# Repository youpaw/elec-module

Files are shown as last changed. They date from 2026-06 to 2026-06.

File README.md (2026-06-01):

# FLIPPER 42 — Electronics Project

A custom device inspired by the Flipper Zero, capable of reading, cloning, and emitting NFC & RFID signals. It features an external coaxial antenna, optional infrared transmission, a custom firmware display, and SD card storage for saved data.

---

## Overview

| Feature | Description |
|---|---|
| **Controls** | 5-button navigation: ◄ ▼ ● ▲ ► (Left, Down, Select, Up, Right) |
| **Power** | 5V DC supply |
| **Storage** | SD card module for firmware and saved signals (NFC dumps, etc.) |
| **Antenna** | External coaxial antenna |
| **Additional** | IR emitter for infrared signal transmission |

---

## Components

### NFC Reader
**IC:** ST25R3916B-AQWT  
High-performance NFC frontend supporting reader/writer and card emulation modes.  
📄 [Datasheet](https://www.st.com/resource/en/datasheet/st25r3916b.pdf)
### RFID Reader
**IC:** EM4095  
125 kHz RFID transceiver for LF tag reading and writing.  
📄 [Datasheet](https://www.emmicroelectronic.com/sites/default/files/products/datasheets/em4095_ds.pdf)

### SD Card Module
**Part Number:** 1040310811 (Molex)  
Micro SD card socket for firmware storage and signal database.  
📄 [Datasheet](https://www.molex.com/en-us/products/part-detail-pdf/1040310811?display=pdf)

---

## Materials

| Qty | Component | Part Number / Symbol | Notes |
|-----|---|---|---|
| 1 | NFC Transceiver | ST25R3916B-AQWT | |
| 1 | RFID Transceiver | EM4095 | 125 kHz |
| 1 | SD Card Socket | 1040310811 | Molex |
| 1 | Coaxial Antenna | — | External |
| 1 | IR LED / Transmitter | — | Optional |
| 1 | Display Module | — | For custom firmware UI |
| 5 | Tactile Switches | — | Navigation buttons |
| — | Power Regulation | — | 5V input |

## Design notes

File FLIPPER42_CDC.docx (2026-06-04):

CAHIER DES CHARGES

Specifications Document

FLIPPER 42

Portable Multi-Protocol Security Research Device

Project | FLIPPER 42
School | École 42 Paris
Module | Electronics / Embedded Systems
Document type | Cahier des Charges (CDC)
Version | 1.0
Date | June 2026
Status | Draft - for academic validation
Authors | FLIPPER 42 Team - 42 Paris

# Table of Contents

1. Introduction 3

1.1 Project Overview 3

1.2 Scope 3

1.3 Definitions & Abbreviations 3

2. Functional Requirements 4

2.1 Core Functions 4

2.2 Sub-GHz (CC1101) 4

2.3 NFC (ST25R3916) 4

2.4 RFID (EM4095) 4

2.5 User Interface 4

3. Hardware Architecture 5

3.1 System Block Diagram Overview 5

3.2 Microcontroller - ATmega2560 5

3.3 Communication Buses 6

3.4 Power Supply 6

4. Non-Functional Requirements 7

4.1 Physical 7

4.2 Electrical 7

4.3 Software & Firmware 7

4.4 Safety 7

5. Bill of Materials (BoM) 7

6. Implementation Procedure 8

6.1 Development Phases 8

7. Acceptance Criteria & Test Plan 8

7.1 Functional Tests 8

7.2 Compliance Checks 9

8. References & Datasheets 9

9. Notes 9

9.1 Hardware Block Diagram Description 9

# 1. Introduction

## 1.1 Project Overview

The FLIPPER 42 is a portable, open-hardware multifunctional device designed for interaction with various electronic access-control and radio-frequency systems. Inspired by the Flipper Zero, the project explores low-level embedded systems design and RF security research using an alternative hardware architecture built around the ATmega2560 microcontroller.

The device is conceived for:

- Educational purposes and academic training in embedded systems
- Security research and ethical hacking activities
- Reading, cloning, and replaying NFC/RFID credentials on authorised systems
- Sub-GHz radio signal acquisition and controlled reproduction
- Hands-on exploration of hardware security protocols

## 1.2 Scope

This document describes the technical and functional specifications of the FLIPPER 42 hardware platform, covering architecture, communication modules, power supply, firmware behaviour, and acceptance criteria. It serves as the reference baseline for the 42 Paris electronics module validation.

## 1.3 Definitions & Abbreviations

Acronym / Term | Definition
CDC | Cahier des Charges
MCU | Microcontroller Unit
RFID | Radio-Frequency IDentification
NFC | Near-Field Communication
Sub-GHz | Radio frequencies below 1 GHz (e.g. 433 MHz, 868 MHz)
SPI | Serial Peripheral Interface - synchronous serial bus
I2C | Inter-Integrated Circuit - two-wire serial bus
UART | Universal Asynchronous Receiver-Transmitter
BMS | Battery Management System
ADC | Analog-to-Digital Converter
GPIO | General-Purpose Input/Output
EEPROM | Electrically Erasable Programmable Read-Only Memory
LF | Low Frequency (125 kHz RFID band)
HF | High Frequency (13.56 MHz NFC band)

# 2. Functional Requirements

## 2.1 Core Functions

The device shall implement the following primary functions:

1. RF Signal Detection & Identification - detect and classify incoming radio signals in supported bands
1. NFC Credential Reading - read and decode ISO 14443 and ISO 15693 compliant tags at 13.56 MHz
2. RFID Credential Reading - read 125 kHz LF tags using the EM4095 transceiver
3. Data Storage - persist captured payloads, signal recordings, and configurations on microSD
4. Signal Replay - reproduce previously recorded signals upon authorised user action
5. External Expansion - expose hardware interfaces (SPI, UART, GPIO) for optional add-on modules

## 2.2 Sub-GHz (CC1101)

The CC1101 low-power Sub-1 GHz RF transceiver shall support:

- Single-band operation dedicated exclusively to the 433 MHz ISM band
- Serial modes for reading, capturing, and replaying raw RF frames
- A path to a physical coaxial connector for an external 433 MHz antenna
- Communication with the MCU via a 4-wire SPI interface at 3.3 V

## 2.3 NFC (ST25R3916)

The ST25R3916B-AQWT high-performance NFC frontend shall support:

- Reader/Writer mode for ISO 14443-A/B and ISO 15693 tagsAlso @
- Card emulation mode (Type A / Type B)
- Reading, storing, and replaying NDEF messages and raw tag dumps
- Communication with the MCU via SPI at 3.3 V

## 2.4 RFID (EM4095)

The EM4095 125 kHz RFID transceiver shall:

- Read EM4100-compatible and compatible LF tags
- Provide demodulated data via GPIO/UART to the MCU
- Store captured UIDs and data payloads to microSD

## 2.5 User Interface

The device shall provide a 6-button navigation interface:

Button | Direction | Function
◄ | Left | Navigate left / back
▼ | Down | Scroll down / decrease value
● | Select | Confirm / enter
▲ | Up | Scroll up / increase value
► | Right | Navigate right / forward
⮐ | Outside / Isolated | Back / Return

An OLED display (connected via I2C) shall provide a menu-driven interface showing:

- Main menu with module selection
- Real-time signal activity and status
- Stored file browser for saved captures
- Battery level and system status

# 3. Hardware Architecture

## 3.1 System Block Diagram Overview

The hardware architecture is centred on the ATmega2560 MCU and interconnects the following subsystems via dedicated bus protocols as described in the uploaded block diagram:

Subsystem | Interface | Voltage | Notes
MCU - ATmega2560 | Central | 5 V | Main controller, 256 KB Flash, 8 KB SRAM, 4 KB EEPROM
OLED Display | I2C | 3.3/5V | ER-OLED015-2Y, 128×64 px
microSD Card | SPI | 3.3 V | FAT32 formatted; stores captures & config
CC1101 Sub-GHz Transceiver | SPI | 3.3 V | Level-shifted; 433 MHz only; external antenna
ST25R3916 NFC Frontend | SPI | 3.3 V | ISO 14443/15693 reader + card emulation
EM4095 RFID Transceiver | GPIO | 5 V | 125 kHz LF RFID
Battery + BMS | Power | 3.7 V | LiPo cell with protection circuit
USB / UART Bridge | UART | 5 V | PC connectivity, firmware upload
Buttons (5×) | GPIO | 3.3 V | Navigation; debounced in firmware
Level Shifter | Logic | 3.3/5V | Bidirectional; protects 3.3 V peripherals
Voltage Divider / ADC | Analog | Var. | Battery voltage sense via MCU ADC

## 3.2 Microcontroller - ATmega2560

The ATmega2560 (TQFP-100) is the central processing unit. Key specifications:

Parameter | Value
Architecture | 8-bit AVR RISC
Clock speed | Up to 16 MHz (external crystal)
Flash memory | 256 KB (in-system programmable)
SRAM | 8 KB
EEPROM | 4 KB
GPIO | 86 pins
SPI interfaces | 1× hardware SPI (shared with CC1101, SD, NFC)
I2C (TWI) | 1× hardware TWI (OLED)
UART | 4× hardware UART (1 used for USB bridge)
ADC | 16-channel, 10-bit
Timers | 6× (8-bit and 16-bit)
Operating voltage | 4.5 V – 5.5 V

## 3.3 Communication Buses

### 3.3.1 SPI Bus (3.3 V)

A single SPI bus (MOSI, MISO, SCK) serves the CC1101, microSD, and ST25R3916. Each peripheral is independently selected via a dedicated active-low CS (chip select) line driven by the MCU GPIO. The bus operates at 3.3 V logic; a bidirectional level shifter protects all 3.3 V devices from the 5 V MCU outputs.

### 3.3.2 I2C Bus

The I2C bus connects the OLED display to the MCU using standard 400 kHz fast-mode. Pull-up resistors (4.7 kΩ typical) shall be fitted on SDA and SCL lines.

### 3.3.3 UART

UART0 is routed to a USB-to-UART bridge IC (e.g. CH340G or CP2102) for PC connectivity. This enables firmware flashing via avrdude and runtime serial debugging at 115200 baud.

## 3.4 Power Supply

Domain | Source | Regulation | Consumers
5 V main | USB or LiPo via boost | LDO / boost converter | MCU, EM4095, USB bridge
3.3 V rail | AMS1117-3.3 or equiv. | LDO from 5 V | CC1101, NFC, OLED, SD, level shifter
Battery | LiPo 3.7 V / 1000 mAh+ | BMS + protection IC | System supply when off USB

The BMS shall provide over-charge, over-discharge, and short-circuit protection. A voltage divider on the battery line feeds the MCU ADC for state-of-charge estimation.

# 4. Non-Functional Requirements

## 4.1 Physical

Requirement | Target
Weight | TODO < 400g
Enclosure | PCB-mount shell Initially then 3D-printed
Connector | USB-C or Micro-USB for power and programming

## 4.2 Electrical

Requirement | Target
Supply input | 5 V via USB; 3.7 V LiPo battery
3.3 V rail | +-5% tolerance
Autonomy | TODO

## 4.3 Software & Firmware

- Firmware written in C using the “avr” library toolchain
- Menu-driven OLED interface with 5-button navigation
- FAT32 filesystem on microSD
- UART debug console at 115200 baud accessible via USB

## 4.4 Safety

The FLIPPER 42 shall be operated exclusively in compliance with applicable radio regulations.

The device is intended for educational and security research only.

# 5. Bill of Materials (BoM)

The following table lists the principal components identified for the FLIPPER 42 prototype. Quantities are for a single unit.

Qty | Component | Part Number | Interface | Notes
1 | MCU | ATmega2560-16AU | SPI/I2C/UART/GPIO | Main controller, TQFP-100
1 | Sub-GHz Transceiver | CC1101 | SPI 3.3 V | 433 MHz; external antenna
1 | NFC Frontend | ST25R3916B-AQWT | SPI 3.3 V | ISO 14443 / 15693
1 | RFID Transceiver | EM4095 | GPIO 5 V | 125 kHz LF RFID
1 | OLED Display | ER-OLED015-2 | I2C | 128×64 px
1 | microSD Socket | 1040310811 (Molex) | SPI 3.3 V | FAT32; micro-SD
1 | 3.3 V LDO | AMS1117-3.3 | Power | 300 mA min.
1 | Battery BMS | | Power | LiPo protection
1 | LiPo Battery | 3.7 V / 1000+ mAh | Power | Rechargeable
1 | Coaxial Antenna | 433 MHz SMA | RF | External removable
5 | Tactile Switches | Generic 6×6 mm | GPIO | Navigation buttons
-- | Passives (R, C, L) | Various | PCB | Per datasheet values

# 6. Implementation Procedure

## 6.1 Development Phases

Phase | Activity | Deliverable
1 - Design | Schematic capture, component selection, BOM validation | Schematic PDF, BoM spreadsheet
2 - PCB Layout | Routing, DRC KiCad Files | PCB fabrication order
3 - Prototyping | Breadboard / protoboard assembly and initial power-on | Powered prototype, voltage checks
4 - Firmware | Development per module (CC1101, NFC, RFID, SD) | Firmware repo, unit tests
5 - Integration | System integration, module interaction, OLED UI | Working integrated prototype
6 - Validation | Functional test against acceptance criteria | Test report
7 - Documentation | CDC finalisation, code documentation, README | Final CDC PDF, GitHub

# 7. Acceptance Criteria & Test Plan

## 7.1 Functional Tests

Test ID | Module | Procedure | Expected Result | Pass Criteria
T-01 | Power | Apply 5 V USB; measure 5 V and 3.3 V rails | Both rails within ±5% | Voltmeter reading in spec
T-02 | MCU | Flash blink firmware; observe LED | LED blinks at 1 Hz | Visible blink
T-03 | OLED | Flash display test; observe screen | All pixels lit, menu displayed | Visual Confirmation
T-04 | SD Card | Write and read test file via firmware | File written and read back correctly | Data integrity 100%
T-05 | CC1101 | Capture 433 MHz remote signal; display capture | Signal captured and stored on SD | Valid file on SD card
T-06 | CC1101 | Replay stored 433 MHz signal to target device | Target device responds | Repeatable successful replay
T-07 | NFC | Read ISO 14443-A tag; display UID on OLED | UID displayed correctly | Matches reference reader
T-08 | RFID | Read EM4100 125 kHz tag; display data | Tag data displayed correctly | Matches reference reader
T-09 | Battery | Operate 4 h on battery; monitor voltage | Device operational for ≥ 4 h | No shutdown under load
T-10 | Buttons | Press each button; verify OLED response | Correct navigation action per button | All 6 buttons functional

## 7.2 Compliance Checks

- All RF transmissions verified to comply with 433 MHz ISM band limits
- Device shall not transmit on unauthorised frequencies

# 8. References & Datasheets

Document | Source
ATmega2560 Datasheet | https://www.microchip.com/en-us/product/atmega2560
CC1101 Datasheet | https://www.ti.com/lit/ds/symlink/cc1101.pdf?ts=1780550466112
ST25R3916B Datasheet | https://www.st.com/resource/en/datasheet/st25r3916b.pdf
EM4095 Datasheet | https://www.emmicroelectronic.com/sites/default/files/products/datasheets/em4095_ds.pdf
microSD Socket (Molex) | Part 1040310811
Project GitHub Repository | https://github.com/youpaw/elec-module
Flipper Zero Reference | https://flipperzero.one

# 9. Notes

## 9.1 Hardware Block Diagram Description

The following block diagram shows the interconnections for the FLIPPER 42 system.

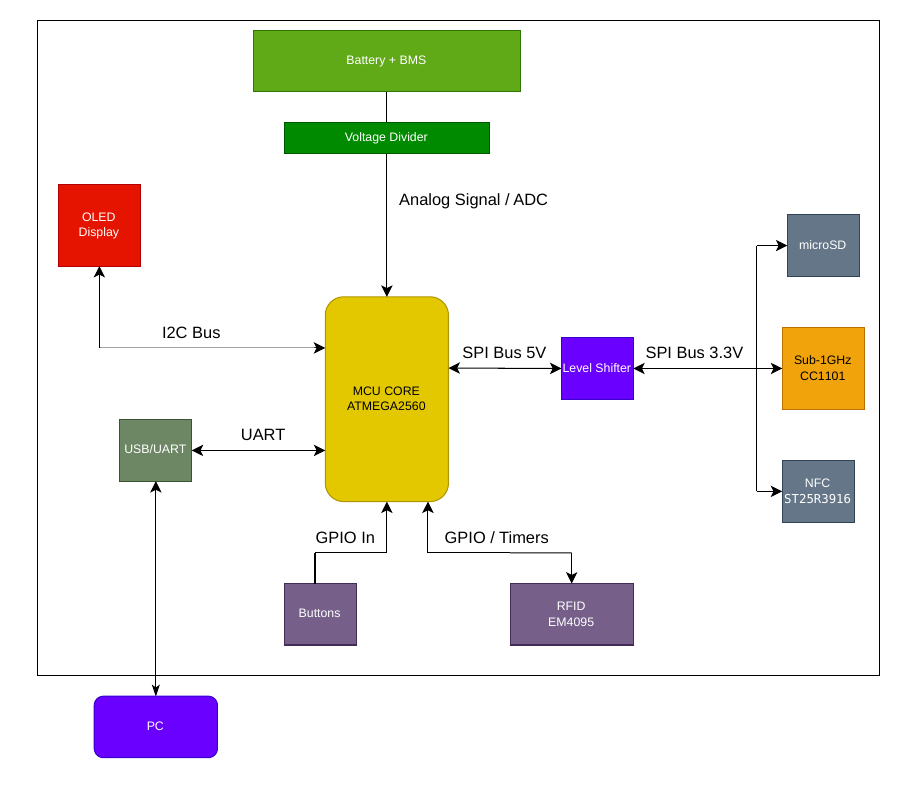
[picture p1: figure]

42Paris Page 11 / 11

FLIPPER 42 - Cahier des Charges (CDC) École 42 Paris

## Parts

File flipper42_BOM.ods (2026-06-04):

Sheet: Sheet1
Item | Designator | Quantity | Value/Part Name | Package / Footprint | Description | Manufacturer | Manufacturer Part Number | Supplier | Supplier Link | Unit Price | Total Price
1 | U1 | 1 | ATMEGA2560 | TQFP-100 | Microcontroller MCU | Microchip
2 | U3 | 1 | TXS0108E | TSSOP-20 | Voltage level shifter | Texas Instrument | TXS0108EPWR
3
4
5
6
7
8
9
10
11
12

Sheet: Sheet2
Item | Designator | Quantity | Value/Part Name | Package / Footprint | Description | Manufacturer | Manufacturer Part Number | Supplier | Supplier Link | Unit Price | Total Price
1 | U2 | 1 | CC1101 |  |  | Texas Instruments
2 | C51 | 1 | Capacitor 100 nF ± 10% | O402
3 | C81, C101 | 2 | Capacitor 27 pF ± 5% | O402
4 | C121 | 1 | Capacitor 3.9pF ± 0.25 pF | O402
5 | C122 | 1 | Capacitor 8.2 pF ± 0.5pF | O402
6 | C123 | 1 | Capacitor5.6 pF ± 0.5pF | O402
7 | C124, C125 | 2 | Capacitor 220 pF ± 5% | O402
8 | C131 | 1 | Capacitor 3.9pF ± 0.25 pF | O402 monolithic | Capacitor monolithic
9 | L121, L123, L131 | 2 | 27 nH ± 5% | O402 monolithic
10 | L122 | 1 | 22 nH ± 5% | O402 monolithic
11 | R171 | 1 | 56 kOhms ± 1% | O402
12 | XTAL | 1 | 26 MHz |  | 26 MHz SMD Crystal
13 |  | 1 | CON-SMA-EDGE-S |  | Connector Coaxial Female Socket Board Edge Mount 50Ohms | RF Solutions | CON-SMA-EDGE-S
14 | Atenna | 1 |  |  | Antenna Whip 433MHz

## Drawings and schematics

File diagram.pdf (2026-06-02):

## Analog Signal / ADC

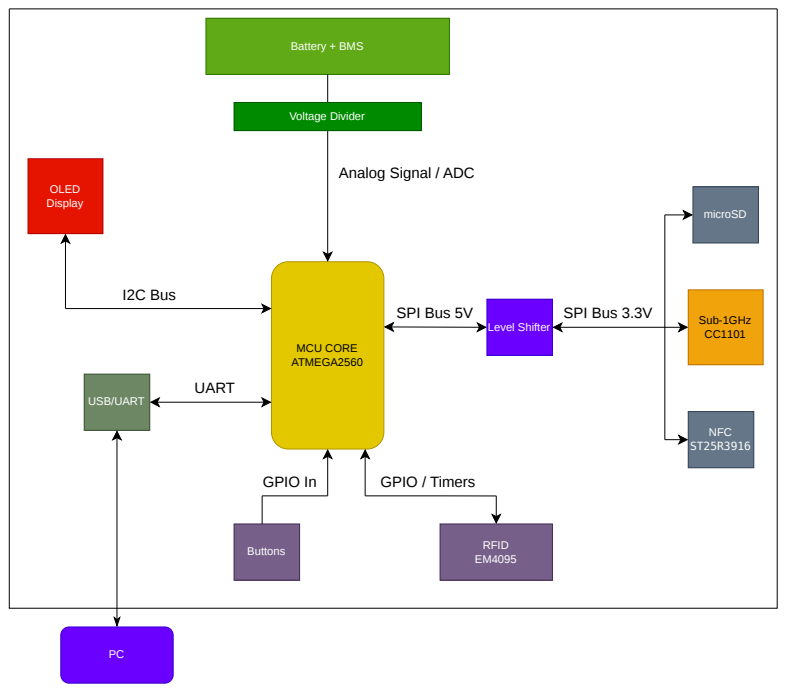
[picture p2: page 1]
MCU CORE ATMEGA2560; OLED Display; I2C Bus; microSD; SPI Bus 5V; Sub-1GHz; Battery + BMS; USB/UART; UART; Buttons; RFID; GPIO In; Level Shifter; Voltage Divider; SPI Bus 3.3V; GPIO / Timers; NFC ST25R3916

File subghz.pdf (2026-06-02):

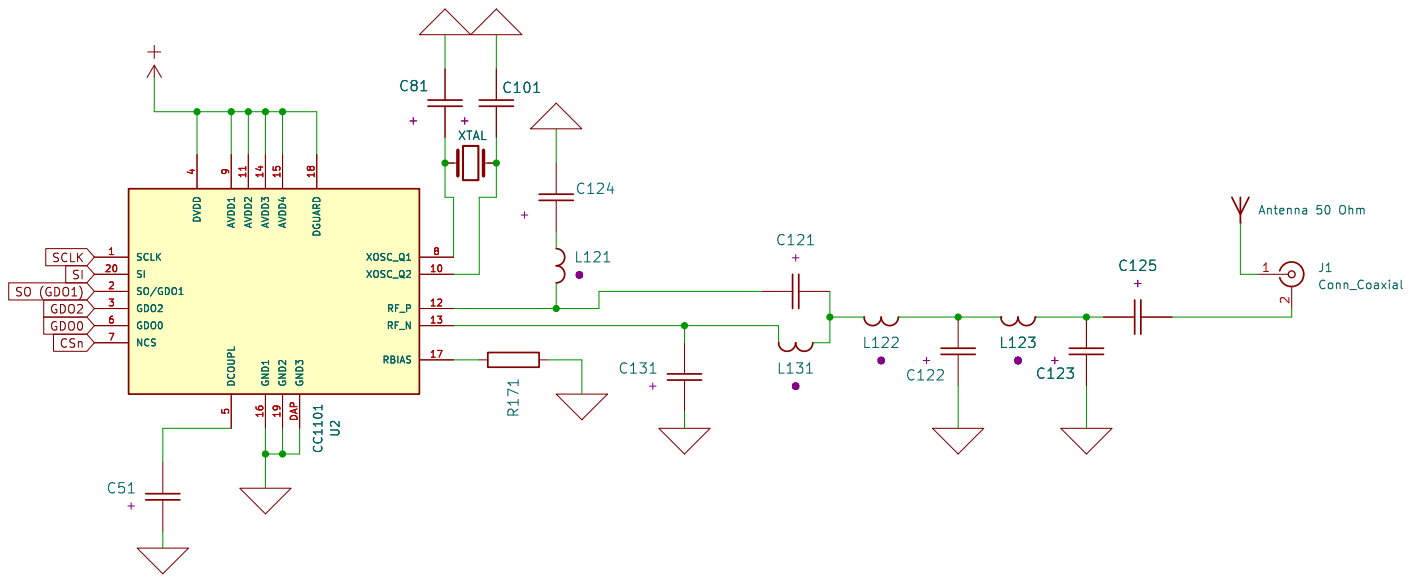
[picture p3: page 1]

Id: 1/1 Title: File: elect_module.kicad_sch Sheet: /

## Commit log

2026-06-01 chore: initialized the KiCad schematics and wrote small README.md
    [flipper42.kicad_pcb, flipper42.kicad_sch]
2026-06-04 Added BOM, changed kicad and updated CDC
    [flipper42.kicad_sch, flipper42_BOM.ods, subghz.kicad_sch]
